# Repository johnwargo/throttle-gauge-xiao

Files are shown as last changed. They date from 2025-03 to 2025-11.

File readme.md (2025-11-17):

# Throttle & Brake Gauge

A simple race car throttle and brake gauge using a strip of NeoPixels and an Adafruit Feather device.

## Background

My friend Scott has a Porsche Boxter he uses for Autocross Racing; you may know Scott as the designer that helps make most of my apps and sites look good. He had a custom throttle gauge made out of a bunch of LEDs mounted under the hood of the car so when he videotaped his runs, he could watch how us uses the throttle and brakes as he works his way through the course.

For a variety of reasons, his existing gauge wasn't working for him; the biggest issue was that he had multiple wires running to each LED and with all the forces operating on the car during a run, LEDs or wire connections were starting to fail.

He asked me if I could help him build a new, more stable version and I did; this project contains the source files for that project.

He essentially wanted two separate gauges: throttle and brakes. He wanted a sort of meter that showed in real-time how hard he was pushing on the accelerator. He also wanted to know when he was pushing on the brakes. 

I decided to use a strip of 25 Adafruit NeoPixel devices, 20 for the throttle and 5 for the brake indicator. 

For the throttle, the 20 LEDs illuminate in sequence, illuminating a single LED green when he pushes lightly on the accelerator and all 20 illuminated when the accelerator's pushed all the way to the floor. At 80% throttle, the LEDs switch from green to white, so on the video recording its easier to see that the accelerator's floored.

For the brake gauge, the gauge is binary, all LEDs on and Red when he depresses the brake pedal and all off when the pedal is not depressed.

## Hardware Components

I built the project using the following components:

+ [Adafruit ESP32-S3 Feather with 4MB Flash 2MB PSRAM](https://www.adafruit.com/product/5477)
+ [Breadboard-friendly RGB Smart NeoPixel - Sheet of 25](https://www.adafruit.com/product/1558)
+ [12V to 5V DC Buck Converter](https://www.amazon.com/Converter-Voltage-Waterproof-Regulator-Step-Down/dp/B07Y2V1F8V) to power the LEDs and Feather device.

## Building the NeoPixel Strip

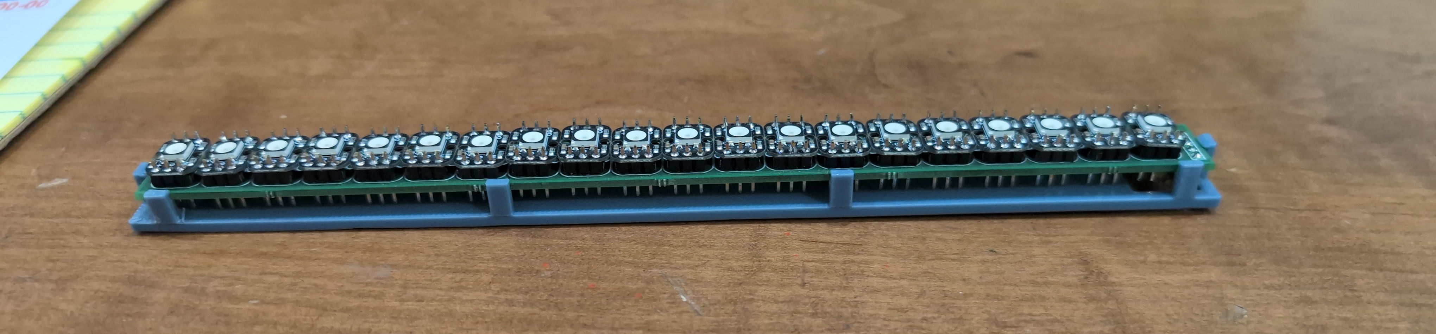
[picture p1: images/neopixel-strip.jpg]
NeoPixel strip


To make the gauge easier to assemble, I created a circuit board for it using [Fritzing](https://fritzing.org/). I always wanted to learn how to design my own circuit boards, so this was my very first. You can find the design for the board in the repository's [Fritzing](Fritzing) folder. 

Rather than manage with the throttle and brake LEDs as a single unit in the code, I decided to separate them in the hardware design. So, the throttle gauge is a strip of 20 interconnected NeoPixels connected to VCC, GND, and one of the digital output pins on the Feather device through header pins on the edge of the circuit board. The brake gauge is 5 interconnected NeoPixels connected the same way, only to a different digital output pin on the Feather device. 

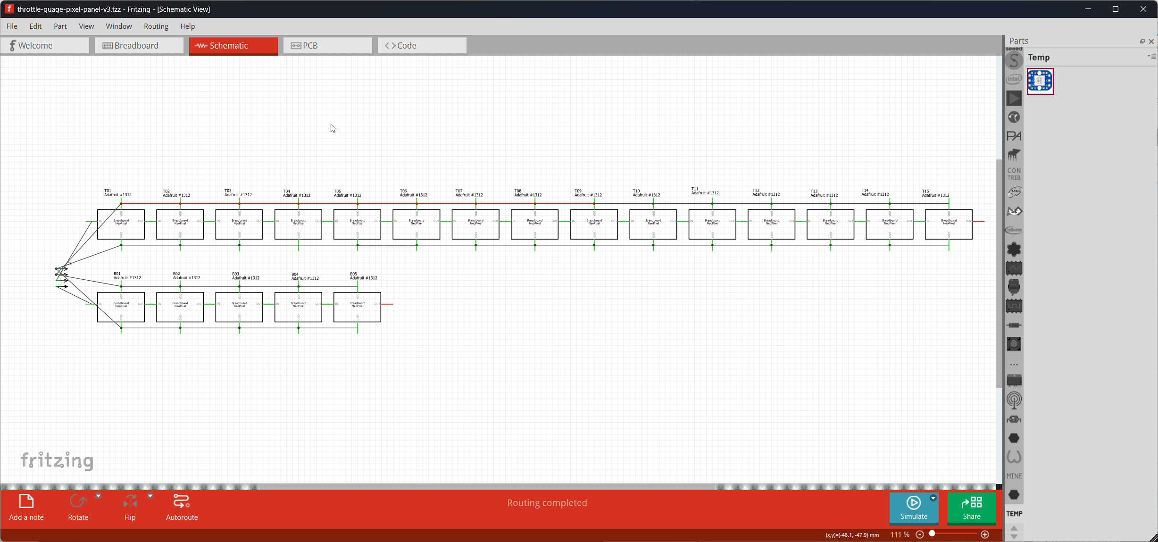
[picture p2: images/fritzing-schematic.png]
Gauge Schematic


This allows me to update the LED arrays separately in the code and not worry about the state of the others. 

Looking at the finished circuit board, it all came together very nicely and neatly.

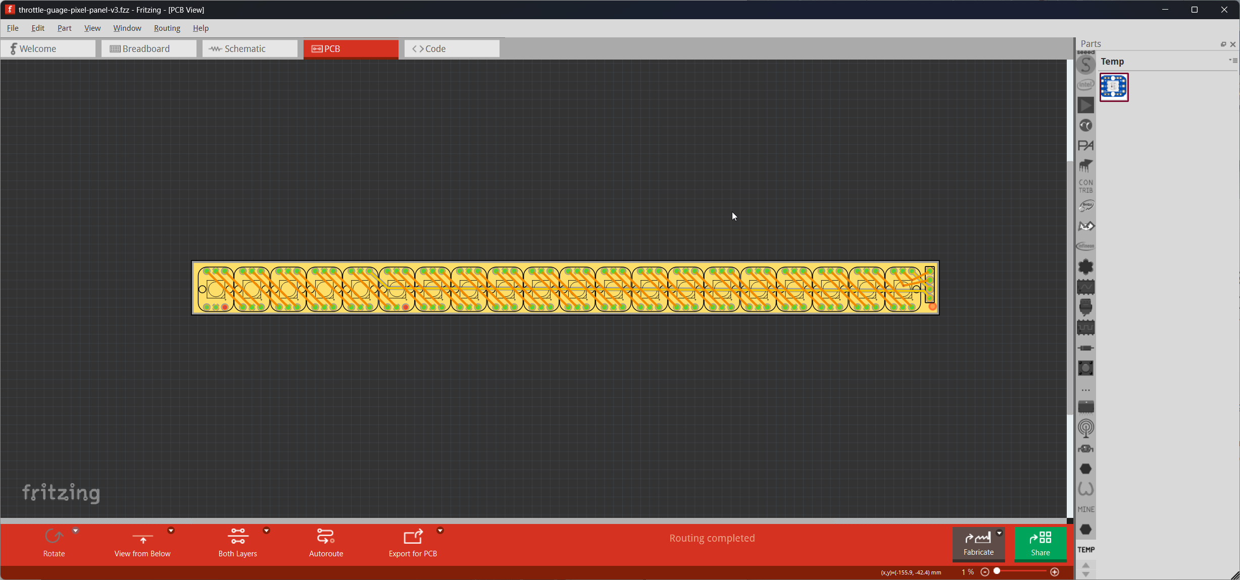
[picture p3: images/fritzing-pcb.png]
Fritzing PCB View


I was able to order professionally produced circuit boards directly from the Fritzing application. Really cool stuff.

Assembling the hardware meant soldering header pins on each of the NeoPixels then soldering each to the circuit board. Very tedious but rewarding. You can see the completed assembly at the top of this document. I soldered a set of header pins to the end of the board for breadboard prototyping, but for the final implementation I soldered 6 feet of wire to the board so we could hide the hardware deep within the car.

## Inputs and Outputs

To change the configuration for your particular hardware configuration, change the following code:

The circuit drives the NeoPixel arrays on the ESP32's digital pins 2 (throttle) and 3 (brake). 

``` c
#define NUM_BRAKE_LEDS 5
#define NUM_THROTTLE_LEDS 15

#define BRAKE_LED_PIN 3
#define THROTTLE_LED_PIN 2
```

The circuit reads the throttle and brake inputs via analog inputs A0 and A1:

``` c
#define INPUT_BRAKE A0
#define INPUT_THROTTLE A1
```

## Measuring High(er) Voltage Inputs

For this car, the throttle output was less than 3v, so measuring it via the analog input pins on the ESP32 wasn't an issue.

The brakes, however, were another issue all together. I didn't have access to the brake pedal switch (I probably could have, but didn't ask), the way the original gauge was setup was to simply measure the output voltage from the wires sending power to the brake lights at the back of the car (which were no longer there). Because of this, to tell if the brakes were on or off I had to look for the presence of ~15V (on) or 0V (off). 

Unfortunately, the ESP32 can't measure 15V so I had to come up with another way to do this.

I implemented a simple Voltage Divider using two resistors as shown below. It converted the maximum 15V input into a 3V input the ESP32 could handle. Cool stuff.

[Voltage Divider](https://ohmslawcalculator.com/voltage-divider-calculator)

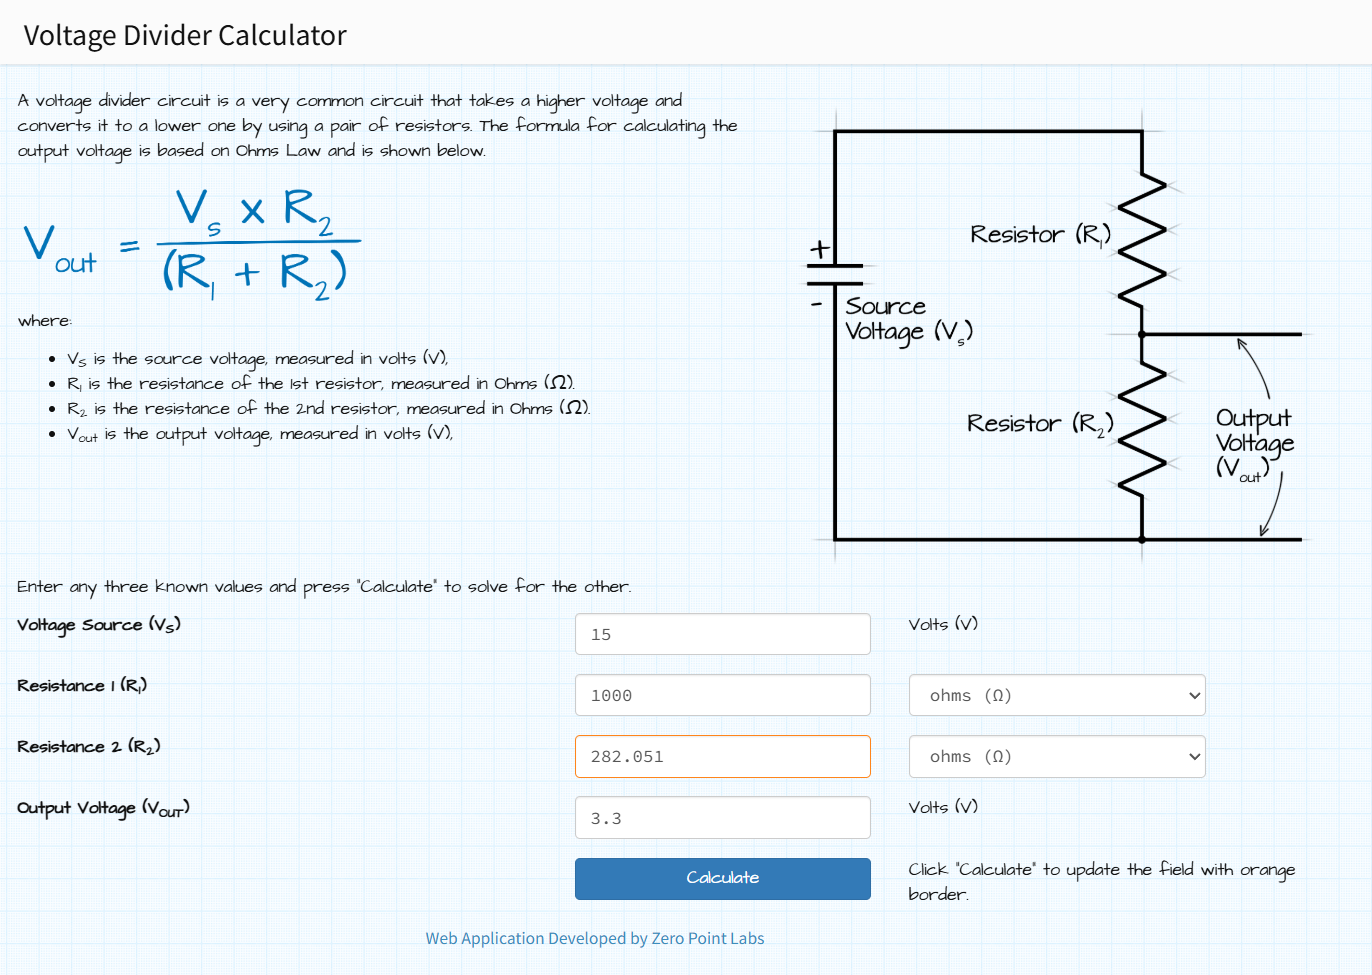
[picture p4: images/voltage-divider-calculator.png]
Voltage Divider Calculator


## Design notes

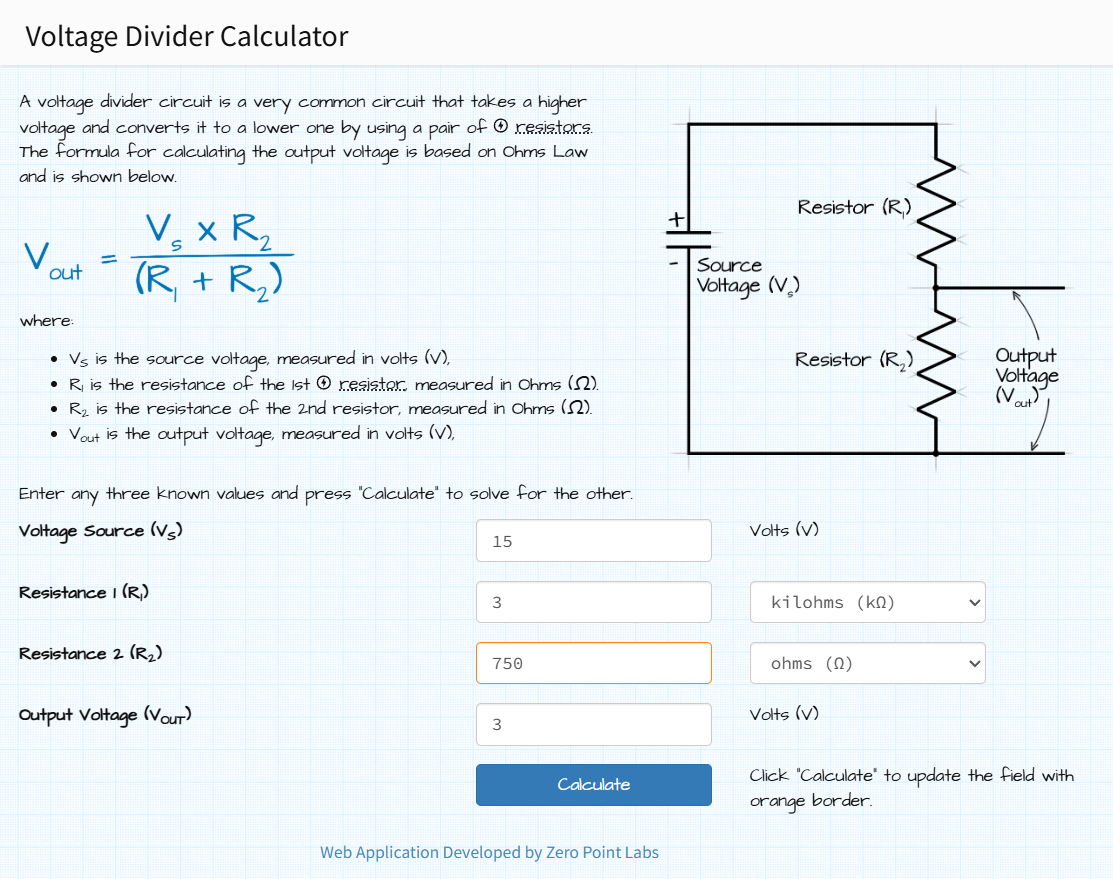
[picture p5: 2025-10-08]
images/voltage-divider-15v.png

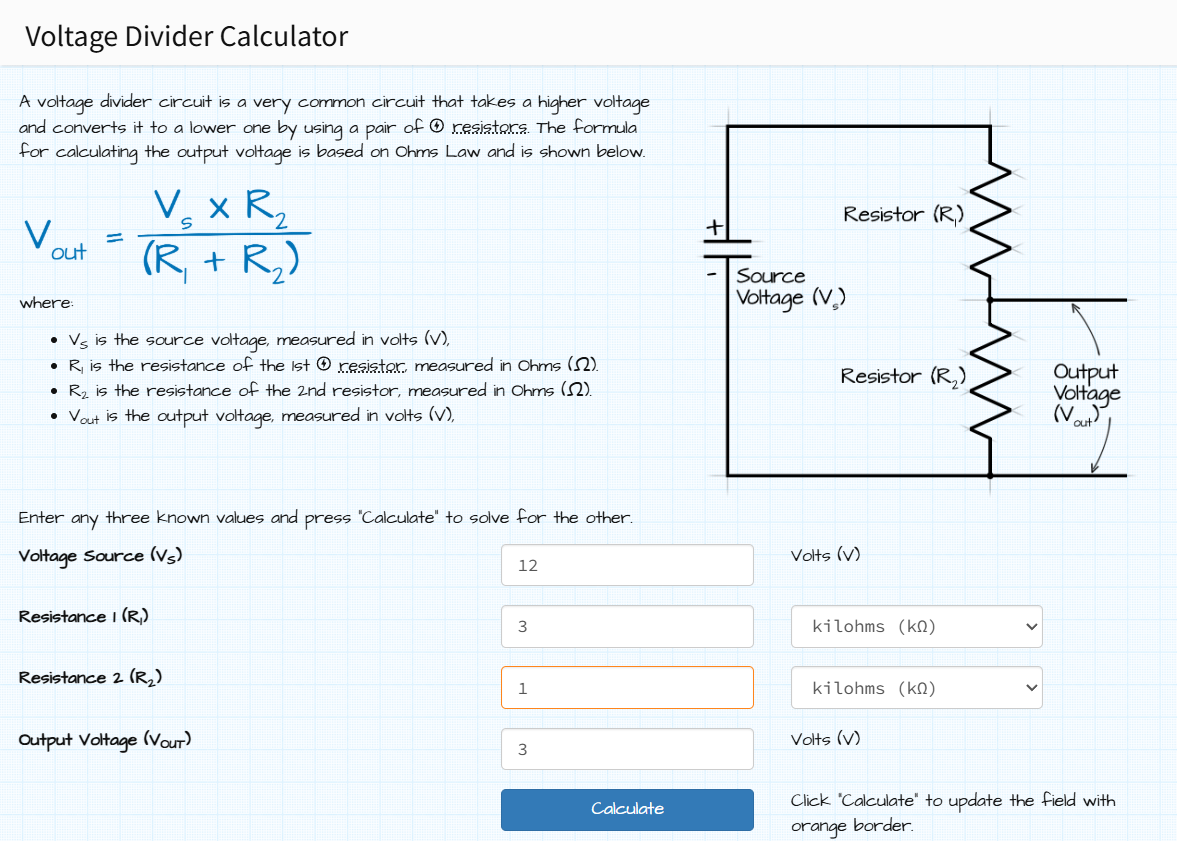
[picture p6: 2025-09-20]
images/voltage-divider-12v.png

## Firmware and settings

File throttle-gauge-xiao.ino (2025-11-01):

/************************************************************
 * Throttle Gauge (XIAO ESP32C6)
 * By John M. Wargo
 * https://johnwargo.com
 * 
 * Created March 3, 2025
 ************************************************************/

#include <FastLED.h>

#define DEBUG

#define NUM_BRAKE_LEDS 5
#define NUM_THROTTLE_LEDS 15

#define BRAKE_LED_PIN 12
#define THROTTLE_LED_PIN 13

#define INPUT_BRAKE A1
#define INPUT_THROTTLE A0
#define THROTTLE_MIN 600

#define testDelay 15  //ms

// FastLED LED Arrays
CRGB tLeds[NUM_THROTTLE_LEDS];
CRGB bLeds[NUM_BRAKE_LEDS];

// The Arduino reads between 0 and 1023 while the ESP32 reads between 0 and 4095
// Adjusts maximum voltage levels read by the device will adjust this based on
// the total voltage output from throttle to ensure we can max out the gauge
// const int inputDivisor = 1023;  // for Arduino devices
// const int inputDivisor = 4095;  // for ESP32 devices
const int inputDivisor = 4095;  // for ESP32 devices
const int brakeThreshold = inputDivisor / 2;

int prevThrottleState = -1;
bool prevBrakeState = false;
bool prevMaxThrottle = false;

void setup() {

  Serial.begin(115200);
  delay(1000);
  Serial.println("\nThrottle Gauge");
  Serial.println("By John M. Wargo\n");

  // make sure we have an appropriate amount of NeoPixels to make a gauge
  if (NUM_THROTTLE_LEDS < 10) {
    Serial.println("\nInvalid Configuration\nNumber of THROTTLE_LEDS must be greater than 9");
    while (true) delay(100);  //loops forever
  }
  if (NUM_BRAKE_LEDS < 1) {
    Serial.println("\nInvalid Configuration\nNumber of BRAKE_LEDS must be greater than 0");
    while (true) delay(100);  //loops forever
  }

  FastLED.setBrightness(255);
  FastLED.addLeds<NEOPIXEL, THROTTLE_LED_PIN>(tLeds, NUM_THROTTLE_LEDS);
  FastLED.addLeds<NEOPIXEL, BRAKE_LED_PIN>(bLeds, NUM_BRAKE_LEDS);

  pinMode(INPUT_THROTTLE, INPUT_PULLDOWN);
  pinMode(INPUT_BRAKE, INPUT_PULLDOWN);

  // test the LEDs, show that they work
  testLEDs();
}

void loop() {
  updateThrottle();
  updateBrake();
  delay(50);
  // testLEDs();
  // delay(1000);
}

void updateThrottle() {

  // Conditions
  // throttle value is the same as previous - do nothing
  // throttle value was greater than 80% and is greater than 80% now - do nothing
  // throttle value is different than last time - update LED state

  int throttleValue;
  int numIlluminatedPixels;
  float pixelRatio;
  bool maxThrottle;
  bool throttleStateChange;

  // read the voltage from the throttle pin
  throttleValue = analogRead(INPUT_THROTTLE);
#ifdef DEBUG
  Serial.printf("Throttle Value: %d\n", throttleValue);
#endif

  // calculate the pixel ratio
  pixelRatio = (float)throttleValue / (float)inputDivisor;
  maxThrottle = pixelRatio >= 0.80;  // 80% or more means max throttle
  // Did the state change in any way?
  throttleStateChange = (throttleValue != prevThrottleState) || (maxThrottle != prevMaxThrottle);
  // reset our `prev` values for next check
  prevThrottleState = throttleValue;
  prevMaxThrottle = maxThrottle;

  if (throttleStateChange) {
    if (maxThrottle) {
      // Set all throttle LEDs to WHITE
      for (int i = 0; i < NUM_THROTTLE_LEDS; i++) tLeds[i] = CRGB::White;
    } else {
      // Set only a portion of the throttle LEDs to Green
      if (throttleValue > THROTTLE_MIN) {
        numIlluminatedPixels = pixelRatio * NUM_THROTTLE_LEDS;
      } else {
        numIlluminatedPixels = 0;
      }
#ifdef DEBUG
      Serial.printf("Pixels: %d\n", numIlluminatedPixels);
#endif
      if (numIlluminatedPixels > 0) {
        // light LEDs green based on the current throttle value
        for (int i = 0; i < numIlluminatedPixels; i++) tLeds[i] = CRGB::Green;
      }
      // then set the rest to black
      for (int i = numIlluminatedPixels; i < NUM_THROTTLE_LEDS; i++) tLeds[i] = CRGB::Black;
    }
    FastLED.show();
  }
}

void updateBrake() {
  CRGB ledColor;
  bool brakeState;

  brakeState = (analogRead(INPUT_BRAKE) > brakeThreshold);
  // do we have a change in brake state?
  if (brakeState != prevBrakeState) {
    prevBrakeState = brakeState;
    // then update the LEDs
    ledColor = (brakeState) ? CRGB::Red : CRGB::Black;
    for (int i = 0; i < NUM_BRAKE_LEDS; i++) bLeds[i] = ledColor;
    FastLED.show();
  }
}

void testLEDs() {
  Serial.println("Testing LEDs");

  FastLED.clear();
  FastLED.show();
  for (int i = 0; i < NUM_THROTTLE_LEDS; i++) {
    Serial.println(i);
    tLeds[i] = CRGB::Green;
    FastLED.show();
    delay(testDelay);
  }
  for (int i = NUM_THROTTLE_LEDS - 1; i > -1; i--) {
    Serial.println(i);
    tLeds[i] = CRGB::Black;
    FastLED.show();
    delay(testDelay);
  }

  for (int i = 0; i < 3; i++) {
    fill_solid(bLeds, NUM_BRAKE_LEDS, CRGB::Red);
    FastLED.show();
    delay(250);
    FastLED.clear();
    FastLED.show();
    delay(100);
  }
}

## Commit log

2025-03-06 Update throttle-gauge-xiao.ino
    Converted divisor to variable
2025-08-12 working away
    [throttle-guage-pixel-panel.fzz]
2025-09-20 switched to feather board
2025-09-30 Update throttle-gauge-xiao.ino
    switched input pins
2025-11-09 added 3d print files folder
2025-11-10 added 3d files
    [gauge bracket.stl, gauge enclosure.stl]
2025-11-14 deleted 3d print files
    [gauge bracket.stl, gauge enclosure.stl]
2025-11-17 Revert "Update throttle-gauge-xiao.ino"
    This reverts commit 5c4f485cc75b57dc07c30175456e53d7fc9ef75a.
    [throttle-gauge-xiao.ino]
2026-02-22 Update throttle-gauge.ino
    Trying to implement Scott's changes
2026-02-22 Update throttle-gauge.ino
    Refactored updating the pixel display
2026-02-24 Update throttle-gauge.ino
    I think (hope) I've got it now.
